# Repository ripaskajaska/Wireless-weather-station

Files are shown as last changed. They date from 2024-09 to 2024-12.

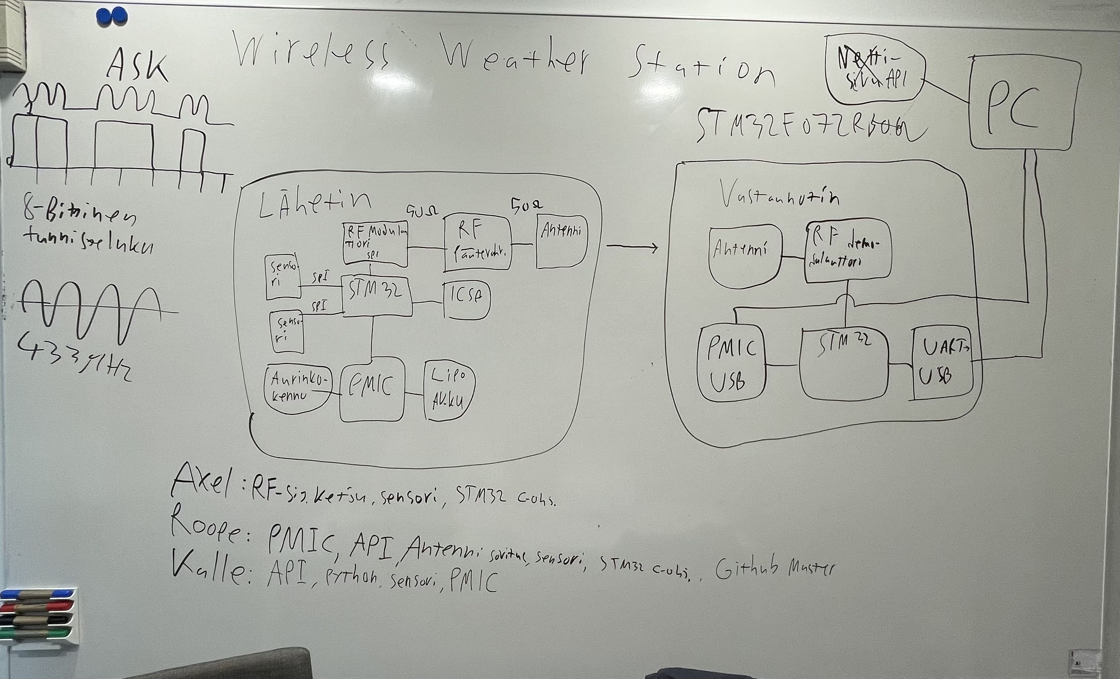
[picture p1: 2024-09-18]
plan_120924.jpeg

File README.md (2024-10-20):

# Wireless-weather-station
Aalto University’s ELEC-8701 Elektronics workshop courses repository for Axel Soderberg, Roope Jaskari and Kalle Aro

# Basic git usage for this project:

Sections 1 to 2 are done on the command line
# 1. Initialization 

If you don't have an ssh key yet follow the instruction in [this link](https://www.howtogeek.com/762863/how-to-generate-ssh-keys-in-windows-10-and-windows-11/)
Add this ssh key to your GitHub SSH keys and proceed.

## clone project
```
git clone git@github.com:<yourusername>/Wireless-weather-station.git
```

Go to the cloned repository > "Wireless-weather-station" (default name)

## Make your own branch
```
git branch <your own branch name here>
```
```
git checkout <your own branch name here>
```
# 2. Working with git

When you want to commit something, first check out the changes you have made.
```
git status
```
After this add the files you'd like to commit

```
git add <your file/folder in the git initialized folder>
```
Commit
```
git commit -m "<your required message here>"
```
And if this is your first push to the git repository use this to also set your upstream:

```
git push --set-upstream origin
```
Otherwise:
```
git push
```

# 3. Merging with main
After a successful commit and push, if you'd like to begin a merge request with your branch and the main branch, navigate to your branch in GitHub from this dropdown:



And then make a pull request here: 



After this, notify the other contributors about the pull request in order to get their approval on the matter. Success!

# In addition one can delete their own branch from the GitHub to start a new addition to the project from a clean table. 
# DO NOT TRY TO DELETE THE MAIN BRANCH!

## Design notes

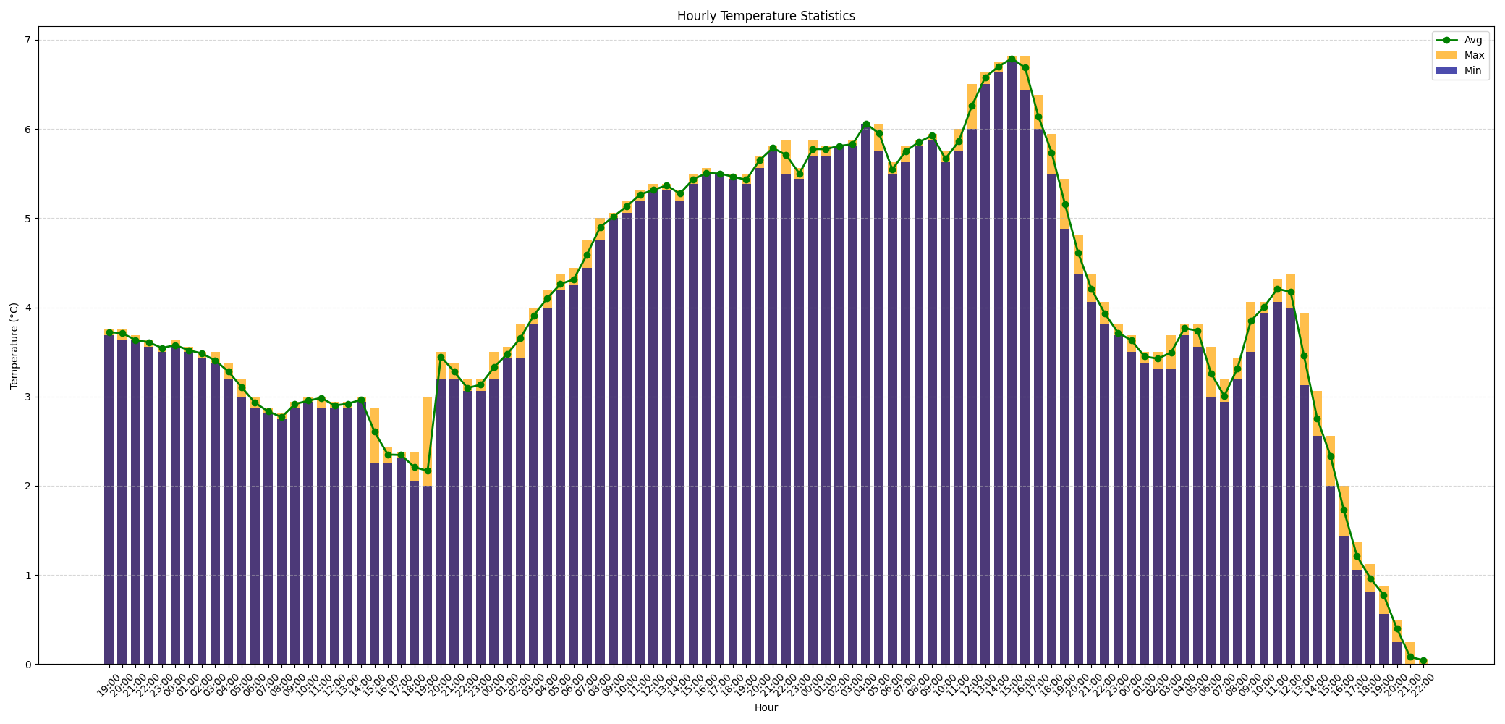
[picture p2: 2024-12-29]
Hrly_temp.png

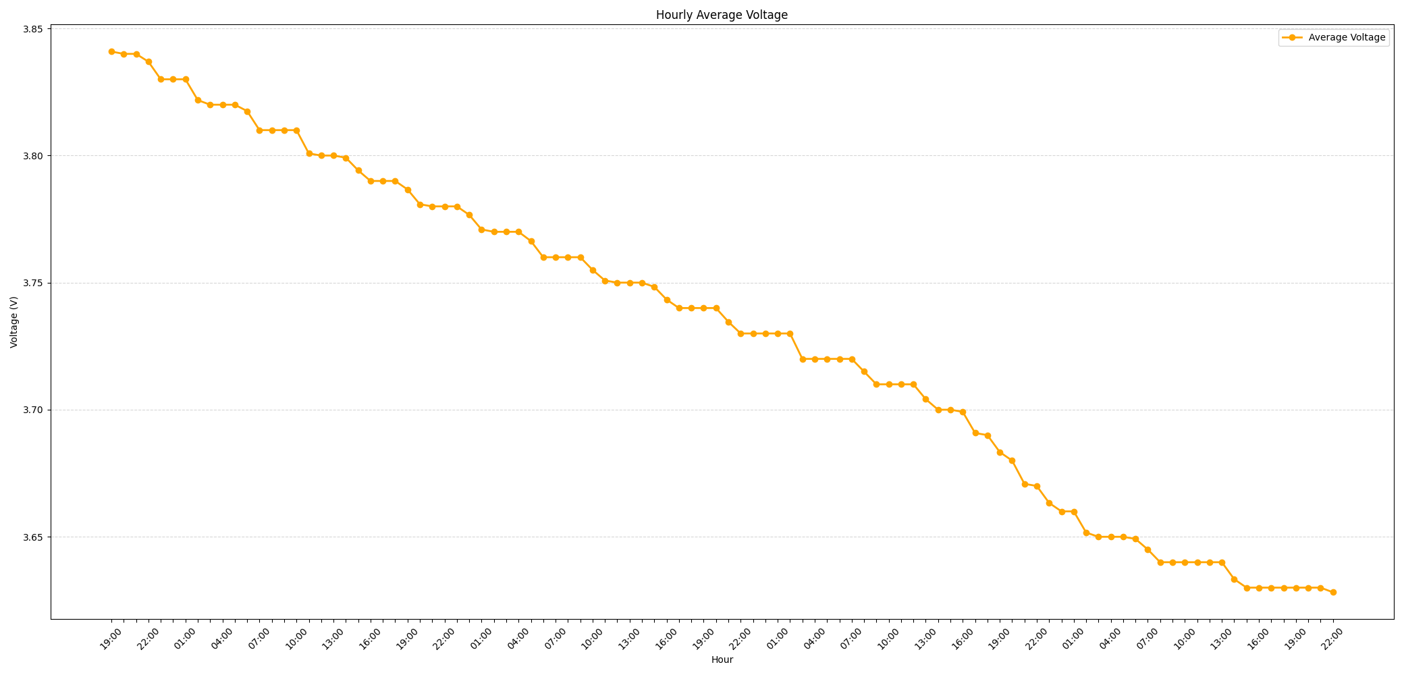
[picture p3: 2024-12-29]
Hrly_avg_vol.png

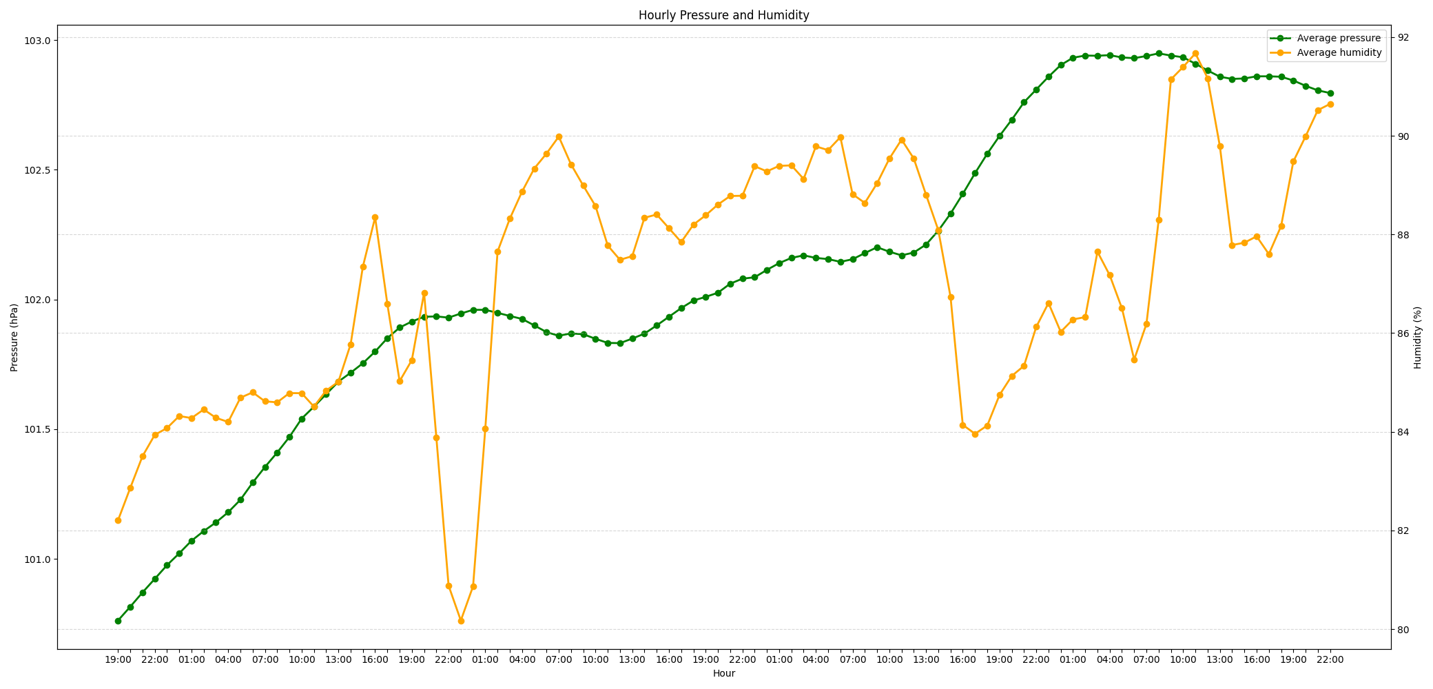
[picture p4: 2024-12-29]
Hrly_avg_pres_and_hum.png

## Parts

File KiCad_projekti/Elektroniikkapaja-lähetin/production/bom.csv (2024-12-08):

Designator | Footprint | Quantity | Value | LCSC Part #
BT1 | BatteryHolder_MPD_BH-18650-PC2 | 1 | Battery_Cell
C1, C2 | 0805 | 2 | 22pF
C10, C17, C21, C22, C4 | 0805 | 5 | 100nF
C11, C12, C15 | 0805 | 3 | 1uF
C13, C20, C6, C7 | 0805 | 4 | 10uF
C14, C16 | 0805 | 2 | 1nF
C18, C19 | 1206 | 2 | 4.7uF
C3 | 0805 | 1 | 4.7pF
C5 | 0805 | 1 | 10pF
C8, C9 | 0805 | 2 | 18pF
D1, D3 | 0805 | 2 | LED
D2 | D_DO-35_SOD27_P7.62mm_Horizontal | 1 | 5.1V Zener
D4 | D_DO-35_SOD27_P7.62mm_Horizontal | 1 | 1N4148
H1, H2, H3, H4 | MountingHole_2.2mm_M2 | 4 | MountingHole
J1 | SMA_Amphenol_901-143_Horizontal | 1 | Conn_Coaxial
J3 | PinHeader_1x06_P2.54mm_Vertical | 1 | Conn_01x06_Pin
J4 | PinHeader_1x04_P2.54mm_Vertical | 1 | Conn_01x04_Pin
J5 | PinSocket_1x07_P2.54mm_Vertical | 1 | Conn_01x07_Socket
J6 | PinHeader_1x02_P2.54mm_Vertical | 1 | Conn_01x02_Pin
J7 | PinHeader_1x08_P2.54mm_Vertical | 1 | Conn_01x08_Pin
J8 | PinHeader_1x02_P2.54mm_Vertical | 1 | Solar_panel_connector
J9 | PinHeader_2x03_P2.54mm_Vertical | 1 | AVR-ISP-6
L1 | 0805 | 1 | 82nH
L2 | 0805 | 1 | 470nF
L3 | WE-PD2_1054 | 1 | 10uH
Q1, Q2 | SOT-23-3 | 2 | SSM3J371R
R1 | 0805 | 1 | 10k
R10, R17 | 0805 | 2 | 2k2
R11 | 0805 | 1 | R
R12 | R_Axial_DIN0204_L3.6mm_D1.6mm_P2.54mm_Vertical | 1 | R_Photo
R13 | 0805 | 1 | 150k
R14 | 0805 | 1 | 300k
R15 | 0805 | 1 | 330r
R16, R18, R19, R20, R21, R4 | 0805 | 6 | 4k7
R2 | 0805 | 1 | 150r
R3, R5, R6 | 0805 | 3 | 1k
R7 | 0805 | 1 | 680mohm
R8 | 0805 | 1 | 160k
R9 | 0805 | 1 | 68k
SW1 | SW_CuK_JS202011CQN_DPDT_Straight | 1 | SW_SPDT
SW_RESET1 | SW_SPST_TL3305A | 1 | SW_Push
U1 | TQFP-44_10x10mm_P0.8mm | 1 | ATmega644-20A
U2 | TSSOP-8_4.4x3mm_P0.65mm | 1 | ~
U3 | SOT-23-6_Handsoldering | 1 | Micrf113
U4 | TO-92_Inline | 1 | MCP1700x-330xxTO
U5 | TO-92_Inline | 1 | DS18S20
U6 | SOT-23-5 | 1 | MCP73831-2-OT
U7 | DIP-14_W7.62mm | 1 | SN74LS07N
Y1 | Crystal_HC49-U_Vertical | 1 | Crystal 16MHz
Y2 | Crystal_HC49-U_Vertical | 1 | Crystal 13.56MHz

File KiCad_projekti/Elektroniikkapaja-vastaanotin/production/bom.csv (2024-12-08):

Designator | Footprint | Quantity | Value | LCSC Part #
C1, C2 | 0805 | 2 | 47pF
C10, C11, C12, C14, C18, C20, C21, C4, C5 | 0805 | 9 | 100nF
C13 | 0805 | 1 | 10uF
C15, C16 | 0805 | 2 | 22pF
C17, C3 | 1206 | 2 | 4.7uF
C19 | 0805 | 1 | 1.2pF
C6, C7 | 0805 | 2 | 1uF
C8, C9 | 0805 | 2 | 10pF
D1, D2, D3, D4, D5 | 0805 | 5 | LED
H1, H2, H3, H4 | MountingHole_2.2mm_M2 | 4 | MountingHole
J1 | USB_B_Lumberg_2411_02_Horizontal | 1 | USB_B
J2 | SMA_Amphenol_901-143_Horizontal | 1 | Conn_Coaxial
J3 | JST_SH_SM04B-SRSS-TB_1x04-1MP_P1.00mm_Horizontal | 1 | Conn_01x04_Pin
J4 | PinHeader_2x03_P2.54mm_Vertical | 1 | AVR-ISP-6
J5 | PinHeader_1x04_P2.54mm_Vertical | 1 | Conn_01x04_Pin
J6 | PinHeader_1x06_P2.54mm_Vertical | 1 | Conn_01x06_Pin
J7 | PinHeader_1x08_P2.54mm_Vertical | 1 | Conn_01x08_Pin
JP1, JP2 | SolderJumper-3_P1.3mm_Open_RoundedPad1.0x1.5mm_NumberLabels | 2 | SolderJumper_3_Open
L2 | 0805 | 1 | 39nH
R1, R2 | 0805 | 2 | 560R
R10, R11, R8, R9 | 0805 | 4 | 4k7
R12 | 0805 | 1 | 10k
R13, R5 | 0805 | 2 | 150r
R3, R4 | 0805 | 2 | 27R
R6 | 0805 | 1 | 100r
R7 | 0805 | 1 | 330r
SW_RESET1 | SW_SPST_TL3305A | 1 | SW_Push
U1 | TQFP-32_7x7mm_P0.8mm | 1 | ATmega328PB-A
U2 | QSOP-16_3.9x4.9mm_P0.635mm | 1 | MICRF220AYQS
U3 | SSOP-16_3.9x4.9mm_P0.635mm | 1 | FT230XS
U4 | TO-92_Inline | 1 | MCP1700x-330xxTO
U5 | SOIC-8_3.9x4.9mm_P1.27mm | 1 | TL072
U6 | DIP-14_W7.62mm | 1 | SN74LS07N
Y1 | Crystal_SMD_HC49-SD_HandSoldering | 1 | 13.52313MHz
Y2 | Crystal_HC49-U_Vertical | 1 | Crystal 16MHz

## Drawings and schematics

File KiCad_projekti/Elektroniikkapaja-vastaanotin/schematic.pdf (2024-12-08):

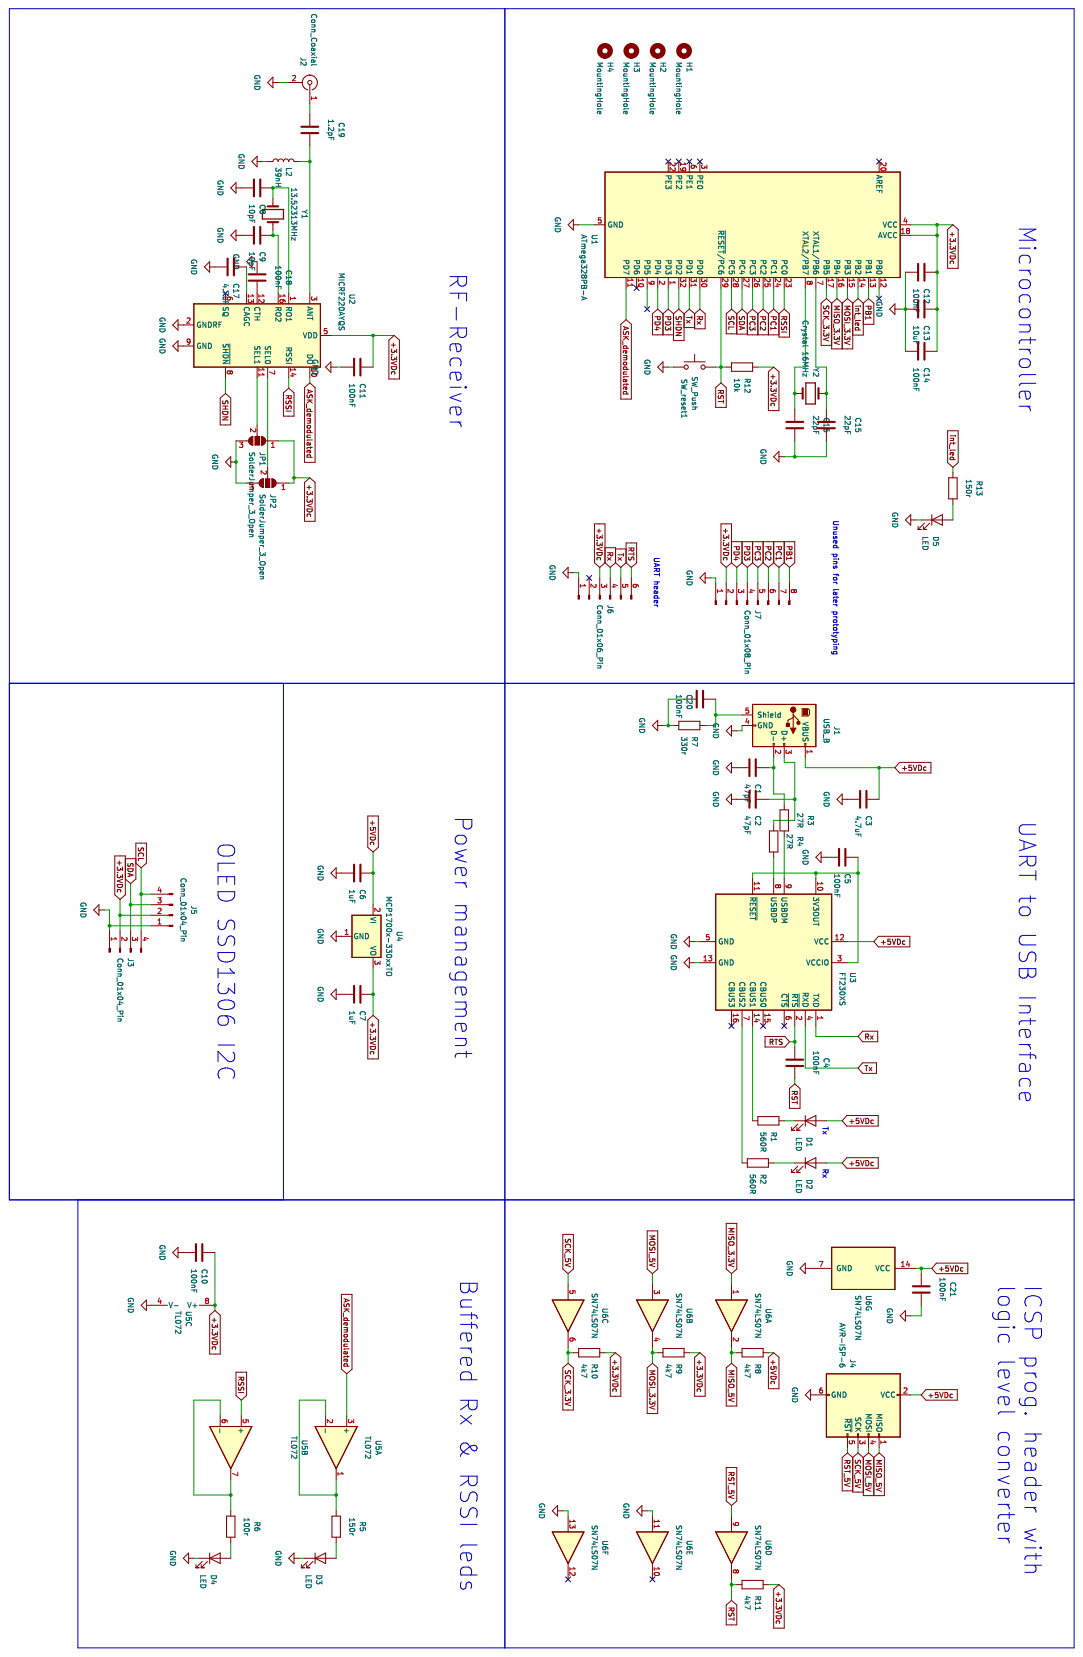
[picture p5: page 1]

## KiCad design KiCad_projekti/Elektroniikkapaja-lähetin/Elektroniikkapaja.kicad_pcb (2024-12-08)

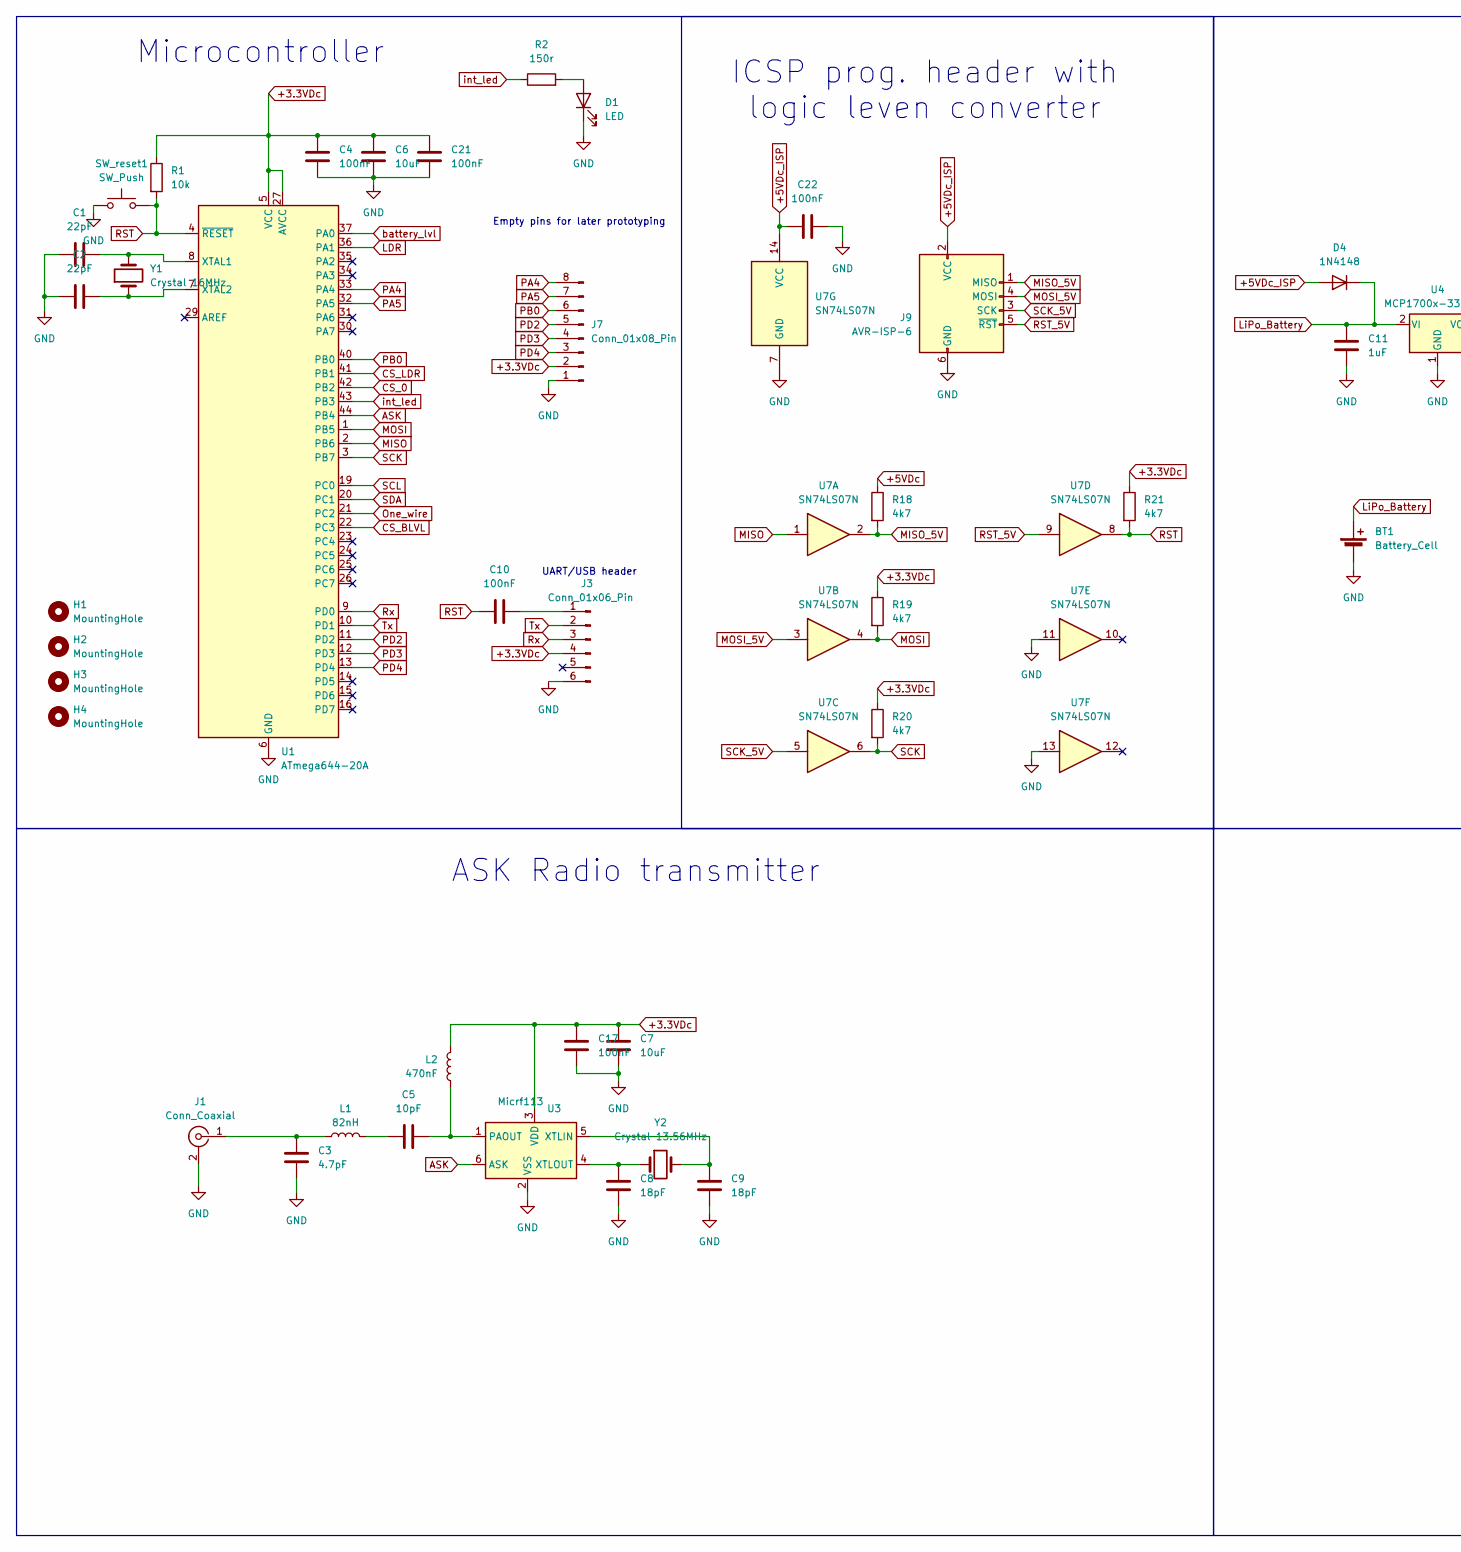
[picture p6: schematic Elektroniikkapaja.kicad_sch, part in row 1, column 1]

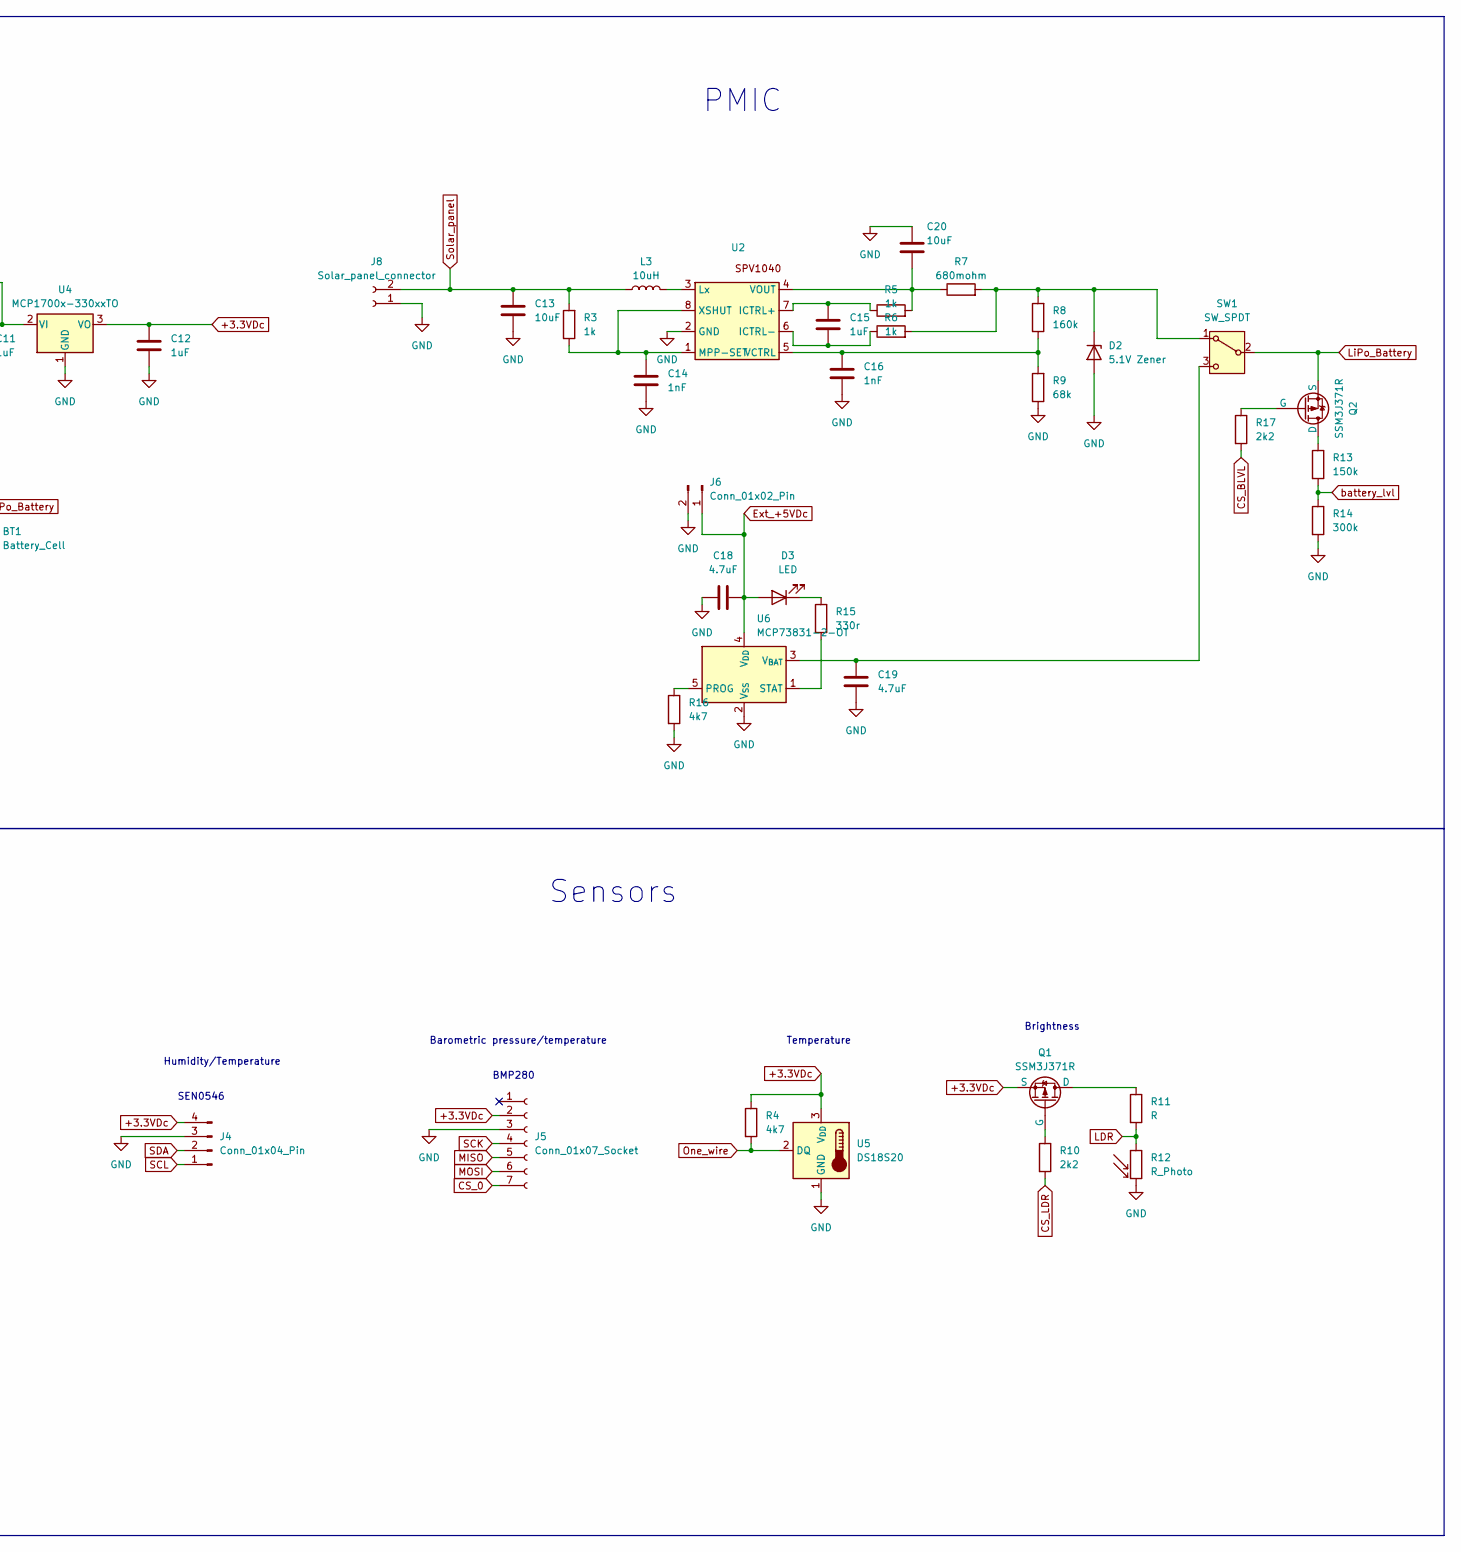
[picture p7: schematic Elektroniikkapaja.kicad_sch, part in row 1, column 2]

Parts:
BT1: Battery_Cell; BatteryHolder_MPD_BH-18650-PC2
C1, C2: 22pF; C_0805_2012Metric_Pad1.18x1.45mm_HandSolder
C3: 4.7pF; C_0805_2012Metric_Pad1.18x1.45mm_HandSolder
C4, C10, C17, C21, C22: 100nF; C_0805_2012Metric_Pad1.18x1.45mm_HandSolder
C5: 10pF; C_0805_2012Metric_Pad1.18x1.45mm_HandSolder
C6, C7, C13, C20: 10uF; C_0805_2012Metric_Pad1.18x1.45mm_HandSolder
C8, C9: 18pF; C_0805_2012Metric_Pad1.18x1.45mm_HandSolder
C11, C12, C15: 1uF; C_0805_2012Metric_Pad1.18x1.45mm_HandSolder
C14, C16: 1nF; C_0805_2012Metric_Pad1.18x1.45mm_HandSolder
C18, C19: 4.7uF; C_1206_3216Metric_Pad1.33x1.80mm_HandSolder
D1, D3: LED; LED_0805_2012Metric_Pad1.15x1.40mm_HandSolder
D2: 5.1V Zener; D_DO-35_SOD27_P7.62mm_Horizontal
D4: 1N4148; D_DO-35_SOD27_P7.62mm_Horizontal
H1, H2, H3, H4: MountingHole; MountingHole_2.2mm_M2
J1: Conn_Coaxial; SMA_Amphenol_901-143_Horizontal
J3: Conn_01x06_Pin; PinHeader_1x06_P2.54mm_Vertical
J4: Conn_01x04_Pin; PinHeader_1x04_P2.54mm_Vertical
J5: Conn_01x07_Socket; PinSocket_1x07_P2.54mm_Vertical
J6: Conn_01x02_Pin; PinHeader_1x02_P2.54mm_Vertical
J7: Conn_01x08_Pin; PinHeader_1x08_P2.54mm_Vertical
J8: Solar_panel_connector; PinHeader_1x02_P2.54mm_Vertical
J9: AVR-ISP-6; PinHeader_2x03_P2.54mm_Vertical
L1: 82nH; L_0805_2012Metric_Pad1.15x1.40mm_HandSolder
L2: 470nF; L_0805_2012Metric_Pad1.15x1.40mm_HandSolder
L3: 10uH; WE-PD2_1054
Q1, Q2: SSM3J371R; SOT-23-3
R1: 10k; R_0805_2012Metric_Pad1.20x1.40mm_HandSolder
R2: 150r; R_0805_2012Metric_Pad1.20x1.40mm_HandSolder
R3, R5, R6: 1k; R_0805_2012Metric_Pad1.20x1.40mm_HandSolder
R4, R16, R18, R19, R20, R21: 4k7; R_0805_2012Metric_Pad1.20x1.40mm_HandSolder
R7: 680mohm; R_0805_2012Metric_Pad1.20x1.40mm_HandSolder
R8: 160k; R_0805_2012Metric_Pad1.20x1.40mm_HandSolder
R9: 68k; R_0805_2012Metric_Pad1.20x1.40mm_HandSolder
R10, R17: 2k2; R_0805_2012Metric_Pad1.20x1.40mm_HandSolder
R11: R; R_0805_2012Metric_Pad1.20x1.40mm_HandSolder
R12: R_Photo; R_Axial_DIN0204_L3.6mm_D1.6mm_P2.54mm_Vertical
R13: 150k; R_0805_2012Metric_Pad1.20x1.40mm_HandSolder
R14: 300k; R_0805_2012Metric_Pad1.20x1.40mm_HandSolder
R15: 330r; R_0805_2012Metric_Pad1.20x1.40mm_HandSolder
SW1: SW_SPDT; SW_CuK_JS202011CQN_DPDT_Straight
SW_reset1: SW_Push; SW_SPST_TL3305A
U1: ATmega644-20A; TQFP-44_10x10mm_P0.8mm
U2: TSSOP-8_4.4x3mm_P0.65mm
U3: Micrf113; SOT-23-6_Handsoldering
U4: MCP1700x-330xxTO; TO-92_Inline
U5: DS18S20; TO-92_Inline
U6: MCP73831-2-OT; SOT-23-5
U7: SN74LS07N; DIP-14_W7.62mm
Y1: Crystal 16MHz; Crystal_HC49-U_Vertical
Y2: Crystal 13.56MHz; Crystal_HC49-U_Vertical

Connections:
+3.3VDc: C4.1, C6.1, C7.1, C12.1, C17.2, C21.1, J3.4, J4.4, J5.2, J7.2, L2.1, Q1.2 (S), R1.1, R4.1, R19.1, R20.1, R21.1, U1.5 (VCC), U1.17 (VCC), U1.27 (AVCC), U1.38 (VCC), U3.3 (VDD), U4.3 (VO), U5.3 (V_{DD})
+5VDc: R18.1
+5VDc_ISP: C22.1, D4.2 (A), J9.2 (VCC), U7.14 (VCC)
ASK: U1.44 (PB4), U3.6 (ASK)
CS_0: J5.7, U1.42 (PB2)
CS_BLVL: R17.2, U1.22 (PC3)
CS_LDR: R10.2, U1.41 (PB1)
Ext_+5VDc: C18.1, D3.2 (A), J6.1, U6.4 (V_{DD})
GND: BT1.2 (-), C1.1, C2.1, C3.2, C4.2, C6.2, C7.2, C8.2, C9.2, C11.2, C12.2, C13.2, C14.2, C16.2, C17.1, C18.2, C19.2, C20.1, C21.2, C22.2, D1.1 (K), D2.2 (A), J1.2 (Ext), J3.6, J4.3, J5.3, J6.2, J7.1, J8.1, J9.6 (GND), R9.1, R12.2, R14.2, R16.2, SW_reset1.1, U1.6 (GND), U1.18 (GND), U1.28 (GND), U1.39 (GND), U2.2 (GND), U3.2 (VSS), U4.1 (GND), U5.1 (GND), U6.2 (V_{SS}), U7.7 (GND), U7.11, U7.13
LDR: R11.2, R12.1, U1.36 (PA1)
LiPo_Battery: BT1.1 (+), C11.1, D4.1 (K), Q2.2 (S), SW1.2 (B), U4.2 (VI)
MISO: J5.5, U1.2 (PB6), U7.1
MISO_5V: J9.1 (MISO), R18.2, U7.2
MOSI: J5.6, R19.2, U1.1 (PB5), U7.4
MOSI_5V: J9.4 (MOSI), U7.3
unnamed: C5.1, L1.2
unnamed: D1.2 (A), R2.2
unnamed: D2.1 (K), R6.2, R7.2, R8.2, SW1.1 (A)
unnamed: D3.1 (K), R15.1
unnamed: C3.1, J1.1 (In), L1.1
unnamed: C10.2, J3.1
unnamed: Q1.3 (D), R11.1
unnamed: Q1.1 (G), R10.1
unnamed: Q2.3 (D), R13.1
unnamed: Q2.1 (G), R17.1
unnamed: C19.1, SW1.3 (C), U6.3 (V_{BAT})
unnamed: C1.2, U1.8 (XTAL1), Y1.2
unnamed: C2.2, U1.7 (XTAL2), Y1.1
unnamed: C15.1, R5.1, U2.7 (ICTRL+)
unnamed: C15.2, R6.1, U2.6 (ICTRL-)
unnamed: L3.2, U2.3 (Lx)
unnamed: C14.1, R3.1, U2.1 (MPP-SET), U2.8 (XSHUT)
unnamed: C16.1, R8.1, R9.2, U2.5 (VCTRL)
unnamed: C20.2, R5.2, R7.1, U2.4 (VOUT)
unnamed: C5.2, L2.2, U3.1 (PAOUT)
unnamed: C9.1, U3.5 (XTLIN), Y2.2
unnamed: C8.1, U3.4 (XTLOUT), Y2.1
unnamed: R16.1, U6.5 (PROG)
unnamed: R15.2, U6.1 (STAT)
One_wire: R4.2, U1.21 (PC2), U5.2 (DQ)
PA4: J7.8, U1.33 (PA4)
PA5: J7.7, U1.32 (PA5)
PB0: J7.6, U1.40 (PB0)
PD2: J7.5, U1.11 (PD2)
PD3: J7.4, U1.12 (PD3)
PD4: J7.3, U1.13 (PD4)
RST: C10.1, R1.2, R21.2, SW_reset1.2, U1.4 (~RESET), U7.8
RST_5V: J9.5 (~RST), U7.9
Rx: J3.3, U1.9 (PD0)
SCK: J5.4, R20.2, U1.3 (PB7), U7.6
SCK_5V: J9.3 (SCK), U7.5
SCL: J4.1, U1.19 (PC0)
SDA: J4.2, U1.20 (PC1)
Solar_panel: C13.1, J8.2, L3.1, R3.2
Tx: J3.2, U1.10 (PD1)
battery_lvl: R13.2, R14.1, U1.37 (PA0)
int_led: R2.1, U1.43 (PB3)

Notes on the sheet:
Temperature
Empty pins for later prototyping
UART/USB header
Microcontroller
Humidity/Temperature
PMIC
Barometric pressure/temperature
BMP280
ICSP prog. header with logic leven converter
ASK Radio transmitter
SEN0546
Brightness
Sensors

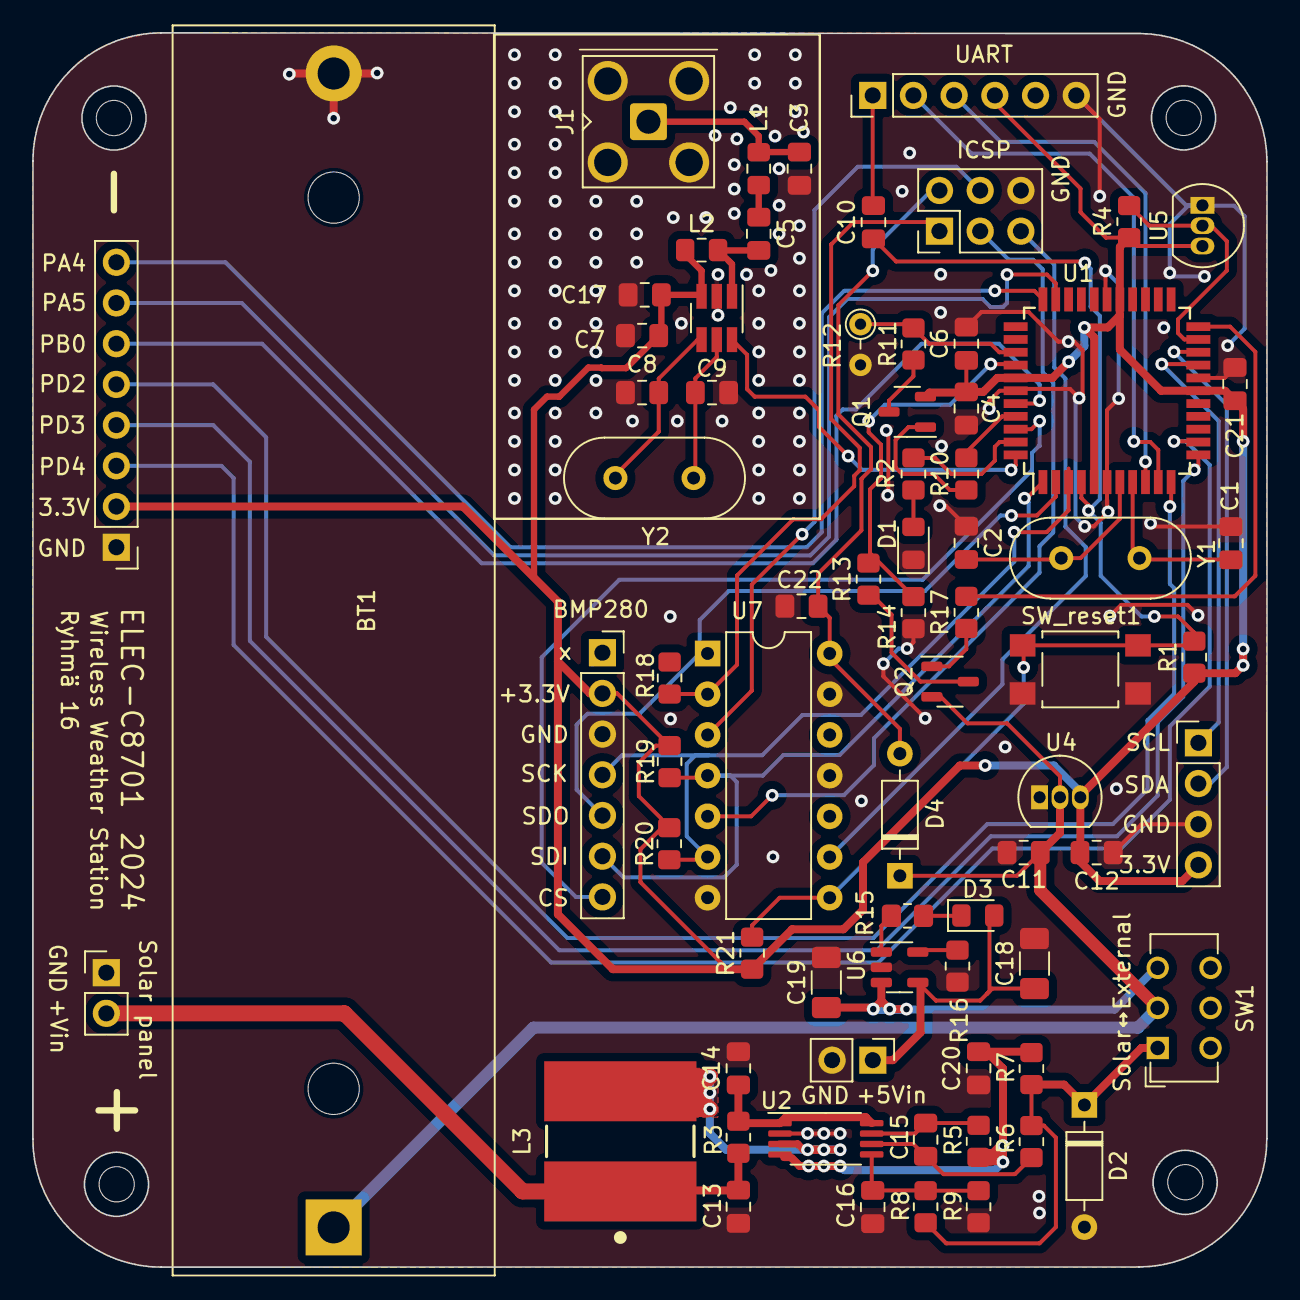
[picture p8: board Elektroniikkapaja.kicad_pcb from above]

Board: 2 copper layers, 77.0 x 77.0 mm, 76 parts (0 on the bottom side), 56 nets.

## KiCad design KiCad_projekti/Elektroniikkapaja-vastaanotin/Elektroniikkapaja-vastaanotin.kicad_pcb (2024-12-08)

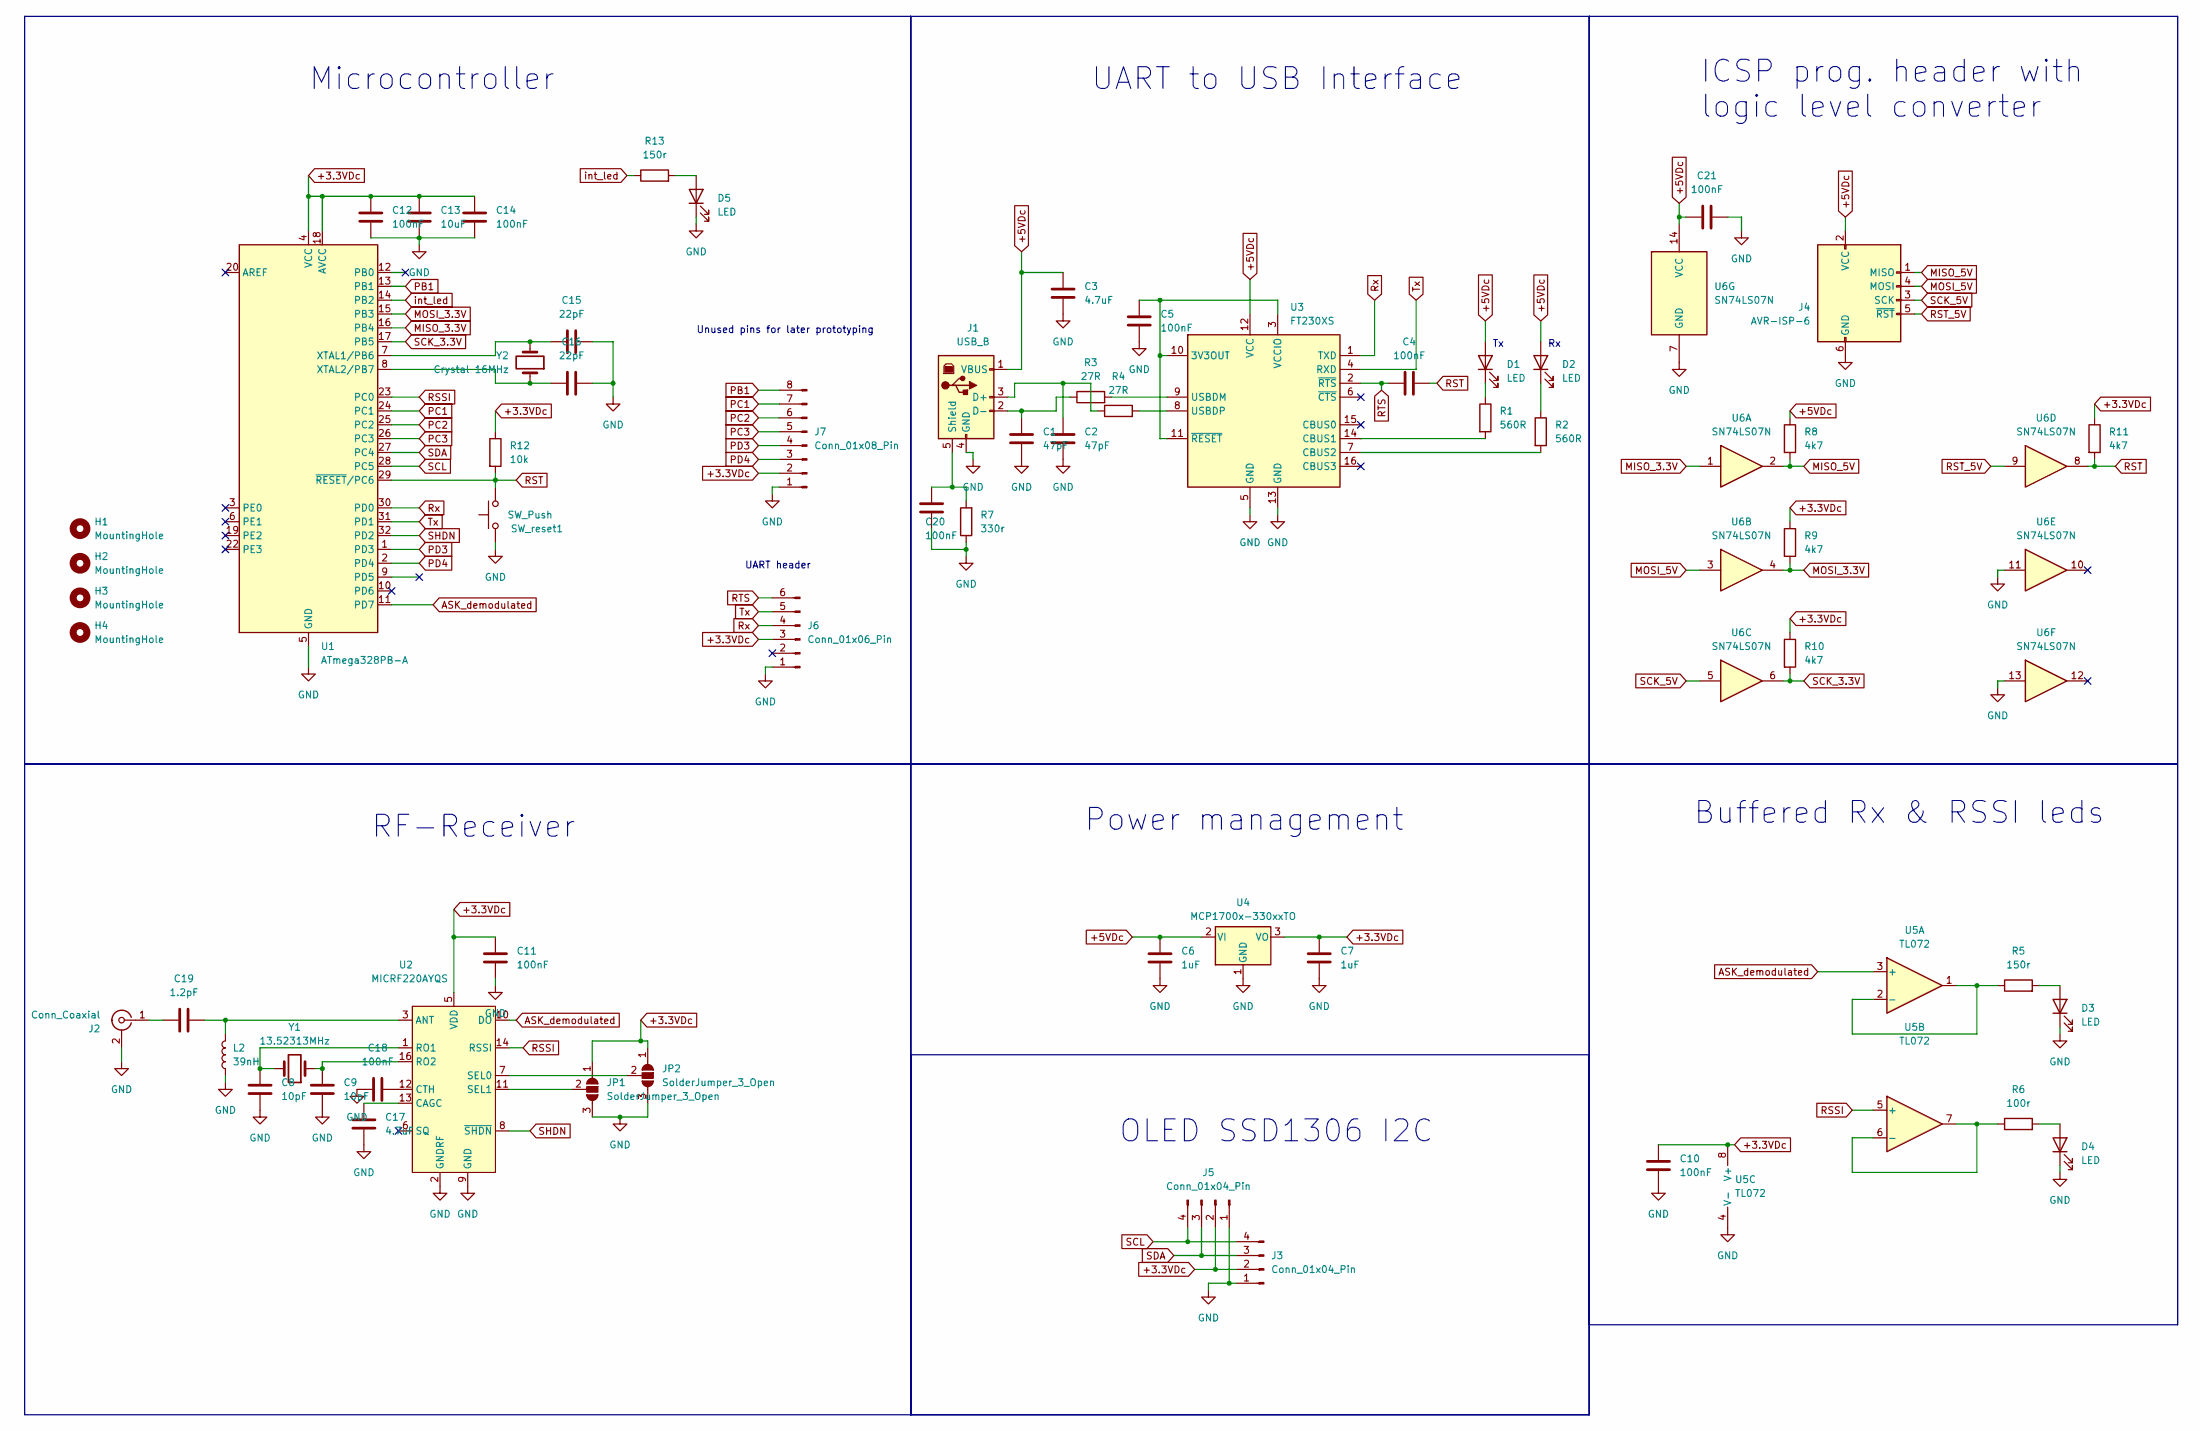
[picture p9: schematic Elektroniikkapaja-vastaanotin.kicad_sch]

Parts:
C1, C2: 47pF; C_0805_2012Metric_Pad1.18x1.45mm_HandSolder
C3, C17: 4.7uF; C_1206_3216Metric_Pad1.33x1.80mm_HandSolder
C4, C5, C10, C11, C12, C14, C18, C20, C21: 100nF; C_0805_2012Metric_Pad1.18x1.45mm_HandSolder
C6, C7: 1uF; C_0805_2012Metric_Pad1.18x1.45mm_HandSolder
C8, C9: 10pF; C_0805_2012Metric_Pad1.18x1.45mm_HandSolder
C13: 10uF; C_0805_2012Metric_Pad1.18x1.45mm_HandSolder
C15, C16: 22pF; C_0805_2012Metric_Pad1.18x1.45mm_HandSolder
C19: 1.2pF; C_0805_2012Metric_Pad1.18x1.45mm_HandSolder
D1, D2, D3, D4, D5: LED; LED_0805_2012Metric_Pad1.15x1.40mm_HandSolder
H1, H2, H3, H4: MountingHole; MountingHole_2.2mm_M2
J1: USB_B; USB_B_Lumberg_2411_02_Horizontal
J2: Conn_Coaxial; SMA_Amphenol_901-143_Horizontal
J3: Conn_01x04_Pin; JST_SH_SM04B-SRSS-TB_1x04-1MP_P1.00mm_Horizontal
J4: AVR-ISP-6; PinHeader_2x03_P2.54mm_Vertical
J5: Conn_01x04_Pin; PinHeader_1x04_P2.54mm_Vertical
J6: Conn_01x06_Pin; PinHeader_1x06_P2.54mm_Vertical
J7: Conn_01x08_Pin; PinHeader_1x08_P2.54mm_Vertical
JP1, JP2: SolderJumper_3_Open; SolderJumper-3_P1.3mm_Open_RoundedPad1.0x1.5mm_NumberLabels
L2: 39nH; C_0805_2012Metric_Pad1.18x1.45mm_HandSolder
R1, R2: 560R; R_0805_2012Metric_Pad1.20x1.40mm_HandSolder
R3, R4: 27R; R_0805_2012Metric_Pad1.20x1.40mm_HandSolder
R5: 150r; R_0805_2012Metric_Pad1.20x1.40mm_HandSolder
R6: 100r; R_0805_2012Metric_Pad1.20x1.40mm_HandSolder
R7: 330r; R_0805_2012Metric_Pad1.20x1.40mm_HandSolder
R8, R9, R10, R11: 4k7; R_0805_2012Metric_Pad1.20x1.40mm_HandSolder
R12: 10k; R_0805_2012Metric_Pad1.20x1.40mm_HandSolder
R13: 150r; R_0805_2012Metric
SW_reset1: SW_Push; SW_SPST_TL3305A
U1: ATmega328PB-A; TQFP-32_7x7mm_P0.8mm
U2: MICRF220AYQS; QSOP-16_3.9x4.9mm_P0.635mm
U3: FT230XS; SSOP-16_3.9x4.9mm_P0.635mm
U4: MCP1700x-330xxTO; TO-92_Inline
U5: TL072; SOIC-8_3.9x4.9mm_P1.27mm
U6: SN74LS07N; DIP-14_W7.62mm
Y1: 13.52313MHz; Crystal_SMD_HC49-SD_HandSoldering
Y2: Crystal 16MHz; Crystal_HC49-U_Vertical

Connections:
+3.3VDc: C7.1, C10.1, C11.1, C12.1, C13.1, C14.1, J3.2, J5.2, J6.3, J7.2, JP1.1 (A), JP2.1 (A), R9.1, R10.1, R11.1, R12.1, U1.4 (VCC), U1.18 (AVCC), U2.5 (VDD), U4.3 (VO), U5.8 (V+)
+5VDc: C3.1, C6.1, C21.1, D1.2 (A), D2.2 (A), J1.1 (VBUS), J4.2 (VCC), R8.1, U3.12 (VCC), U4.2 (VI), U6.14 (VCC)
ASK_demodulated: U1.11 (PD7), U2.10 (DO), U5.3 (+)
GND: C1.2, C2.2, C3.2, C5.2, C6.2, C7.2, C8.2, C9.2, C10.2, C11.2, C12.2, C13.2, C14.2, C15.1, C16.1, C17.2, C18.1, C20.2, C21.2, D3.1 (K), D4.1 (K), D5.1 (K), J1.4 (GND), J2.2 (Ext), J3.1, J4.6 (GND), J5.1, J6.1, J7.1, JP1.3 (B), JP2.3 (B), L2.1, R7.1, SW_reset1.1, U1.5 (GND), U1.21 (GND), U2.2 (GNDRF), U2.4 (GNDRF), U2.9 (GND), U3.5 (GND), U3.13 (GND), U4.1 (GND), U5.4 (V-), U6.7 (GND), U6.11, U6.13
MISO_3.3V: U1.16 (PB4), U6.1
MISO_5V: J4.1 (MISO), R8.2, U6.2
MOSI_3.3V: R9.2, U1.15 (PB3), U6.4
MOSI_5V: J4.4 (MOSI), U6.3
unnamed: D1.1 (K), R1.1
unnamed: D2.1 (K), R2.1
unnamed: D3.2 (A), R5.2
unnamed: D4.2 (A), R6.2
unnamed: D5.2 (A), R13.2
unnamed: C2.1, J1.3 (D+), R4.1
unnamed: C1.1, J1.2 (D-), R3.1
unnamed: C20.1, J1.5 (Shield), R7.2
unnamed: C19.2, J2.1 (In)
unnamed: JP1.2 (C), U2.11 (SEL1)
unnamed: JP2.2 (C), U2.7 (SEL0)
unnamed: C15.2, U1.7 (XTAL1/PB6), Y2.2
unnamed: C16.2, U1.8 (XTAL2/PB7), Y2.1
unnamed: C19.1, L2.2, U2.3 (ANT)
unnamed: C17.1, U2.13 (CAGC)
unnamed: C18.2, U2.12 (CTH)
unnamed: C8.1, U2.1 (RO1), Y1.2
unnamed: C9.1, U2.16 (RO2), Y1.1
unnamed: C5.1, U3.3 (VCCIO), U3.10 (3V3OUT), U3.11 (~RESET)
unnamed: R1.2, U3.14 (CBUS1)
unnamed: R2.2, U3.7 (CBUS2)
unnamed: R3.2, U3.9 (USBDM)
unnamed: R4.2, U3.8 (USBDP)
unnamed: R5.1, U5.1, U5.2 (-)
unnamed: R6.1, U5.6 (-), U5.7
PB1: J7.8, U1.13 (PB1)
PC1: J7.7, U1.24 (PC1)
PC2: J7.6, U1.25 (PC2)
PC3: J7.5, U1.26 (PC3)
PD3: J7.4, U1.1 (PD3)
PD4: J7.3, U1.2 (PD4)
RSSI: U1.23 (PC0), U2.14 (RSSI), U5.5 (+)
RST: C4.2, R11.2, R12.2, SW_reset1.2, U1.29 (~RESET/PC6), U6.8
RST_5V: J4.5 (~RST), U6.9
RTS: C4.1, J6.6, U3.2 (~RTS)
Rx: J6.4, U1.30 (PD0), U3.1 (TXD)
SCK_3.3V: R10.2, U1.17 (PB5), U6.6
SCK_5V: J4.3 (SCK), U6.5
SCL: J3.4, J5.4, U1.28 (PC5)
SDA: J3.3, J5.3, U1.27 (PC4)
SHDN: U1.32 (PD2), U2.8 (~SHDN)
Tx: J6.5, U1.31 (PD1), U3.4 (RXD)
int_led: R13.1, U1.14 (PB2)

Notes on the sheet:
OLED SSD1306 I2C
Unused pins for later prototyping
UART header
Buffered Rx & RSSI leds
ICSP prog. header with logic level converter
UART to USB Interface
RF-Receiver
Power management
Microcontroller

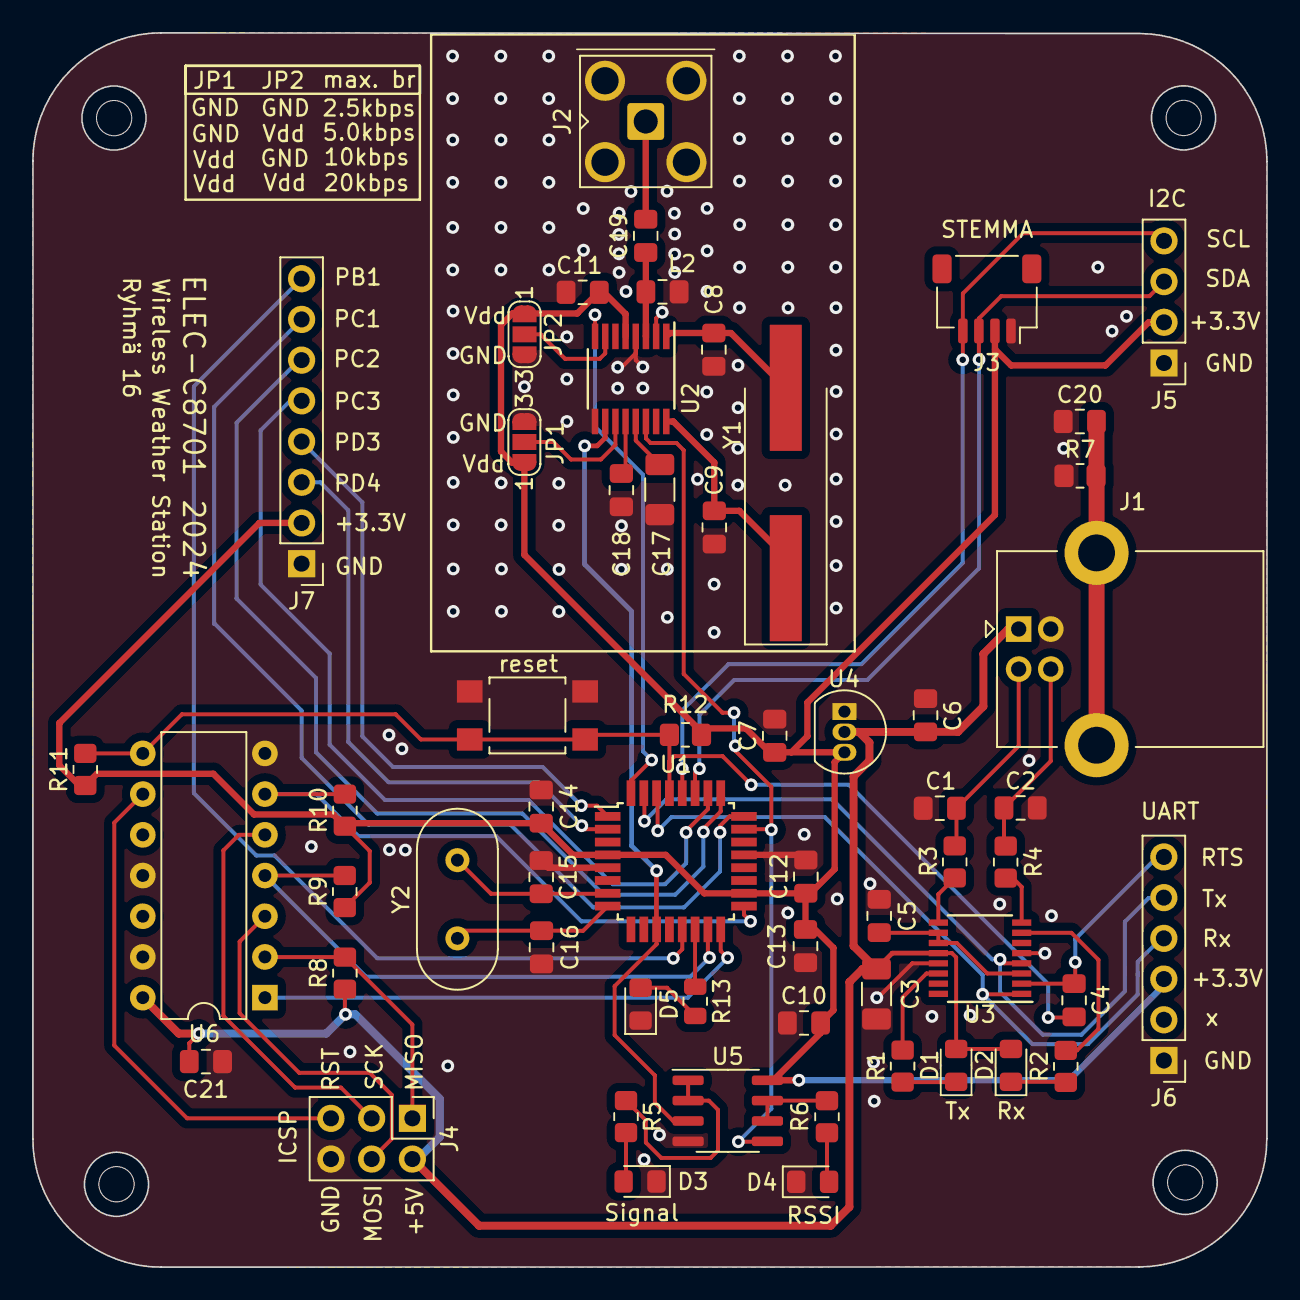
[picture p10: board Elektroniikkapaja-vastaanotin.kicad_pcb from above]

Board: 2 copper layers, 77.0 x 77.0 mm, 62 parts (0 on the bottom side), 51 nets.

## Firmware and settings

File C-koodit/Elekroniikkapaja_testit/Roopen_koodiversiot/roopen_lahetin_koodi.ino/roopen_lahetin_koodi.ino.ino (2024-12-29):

#include <OneWire.h>
#include <RH_ASK.h>
#include <DallasTemperature.h>
#include <Adafruit_BMP280.h>
#include <Wire.h>
#include <SPI.h>
#include <avr/io.h>
#include <avr/interrupt.h>
#include <avr/sleep.h>


// Pin definitions for ATmega644A
#define ONE_WIRE_BUS 18         // For Dallas DS1820
#define BMP_CS PB2               // Use PB4 as Chip Select for BMP280
#define ADDRESS 0x40             // SEN0546 I2C address

// Global variables
float temp = 0.0;
float pressure = 0.0;
float humidity = 0.0;
float battery_voltage = 0.0;
uint8_t buf[4] = {0};
float floatValueArray[4] = {0.0};
uint16_t rawHumidity;
volatile uint16_t timerOverflowCount = 0;  // Overflow counter


// Initialize Dallas Temp DS1820
OneWire oneWire(ONE_WIRE_BUS);        // OneWire instance
DallasTemperature sensors(&oneWire); // Dallas Temperature instance

// Initialize BMP280
Adafruit_BMP280 bmp(BMP_CS); // Hardware SPI

// Create an instance of the RadioHead driver
RH_ASK driver(2000, PA2, 4, PA3);  // (bitrate, RX pin, TX pin, PTT pin)

// Function to send a float array

// Function prototypes
void measure_temperature(float* temp_ptr);
void measure_barometric_pressure(float* pressure_ptr);
void measure_relative_humidity(float* humidity_ptr);
void measure_battery_voltage(float* battery_voltage_ptr);
uint8_t readReg(uint8_t reg, void* pBuf, size_t size);

void sendFloatArray() {
  driver.send((uint8_t*)floatValueArray, 4 * sizeof(float));
  driver.waitPacketSent();
}

void setupTimer1() {
    cli(); // Disable interrupts
    // Configure Timer1
    TCCR1B |= (1 << CS12) | (1 << CS10); // Prescaler = 1024
    TIMSK1 |= (1 << TOIE1);              // Enable Timer1 Overflow Interrupt
    TCNT1 = 0;                           // Reset the timer counter
    sei(); //enable interrupts
}

// Interrupt Service Routine for Timer1 Overflow
ISR(TIMER1_OVF_vect) {
    timerOverflowCount++;  // Increment the overflow counter
}

void waitForMinute() {
    const uint16_t requiredOverflows = (60) / 4.194; // Calculate required overflows (~14 for 16MHz clock)

    timerOverflowCount = 0; // Reset the counter
    set_sleep_mode(SLEEP_MODE_IDLE); // Use Idle mode for sleep

    while (timerOverflowCount < requiredOverflows) {
        // Enable sleep mode
        sleep_enable();

        // Enter sleep mode
        sleep_cpu();

        // MCU wakes up here when Timer1 interrupt triggers
        sleep_disable();
    }
    // Timer reached 1 minute, continue execution
}


void setup() {
  // Initialize Serial for debugging
  Serial.begin(9600);
  while (!Serial);

  
  // Initialize I2C
  Wire.begin(); // This uses PC0 (SCL) and PC1 (SDA) by default on ATmega644A

  // Initialize the RadioHead driver
  driver.init();

  // Initialize sensors
  sensors.begin();

  setupTimer1();

  if (!bmp.begin(BMP_CS)) { // Initialize BMP280 with SPI
    Serial.println("Error: BMP280 not found!");
    while (1); // Halt if BMP280 initialization fails
  }

  bmp.setSampling(Adafruit_BMP280::MODE_FORCED,
                  Adafruit_BMP280::SAMPLING_X2,
                  Adafruit_BMP280::SAMPLING_X16,
                  Adafruit_BMP280::FILTER_X16,
                  Adafruit_BMP280::STANDBY_MS_500);

  // Indicate setup completion
  Serial.println("Setup completed. Starting measurements...");
  pinMode(BMP_CS, OUTPUT);
  pinMode(19, OUTPUT);
  pinMode(3, OUTPUT);
  digitalWrite(3, HIGH);
}

void loop() {
  // Measure temperature
  measure_temperature(&temp);
  if (temp == -127.0) {
    Serial.println("Error: Failed to read DS1820 temperature sensor. Retrying...");
  } else {
    Serial.println("lämpö mitattu");
  }
  floatValueArray[0] = temp;

  // Measure barometric pressure
  measure_barometric_pressure(&pressure);
  Serial.println("paine mitattu");
  floatValueArray[1] = pressure;


  // Measure relative humidity
  measure_relative_humidity(&humidity);
  Serial.println("kosteus mitattu");
  floatValueArray[2] = humidity;

  // Measure battery voltage
  measure_battery_voltage(&battery_voltage);
  Serial.println("akun jännite mitattu");
  floatValueArray[3] = battery_voltage;

  // Print results to Serial Monitor
  Serial.println("Sensor Readings:");
  Serial.print("Temperature (C): ");
  Serial.println(temp);
  Serial.print("Pressure (Pa): ");
  Serial.println(pressure);
  Serial.print("Humidity (%): ");
  Serial.println(humidity);
  Serial.print("Battery Voltage (V): ");
  Serial.println(battery_voltage);

  sendFloatArray();
  digitalWrite(3, HIGH);
  delay(5);  // Wait for a second before sending again
  digitalWrite(3, LOW);
  waitForMinute();
}

// Function to measure temperature
void measure_temperature(float* temp_ptr) {
  sensors.requestTemperatures();
  *temp_ptr = sensors.getTempCByIndex(0);
  // Retry logic for invalid readings
  if (*temp_ptr == -127.0) {
    delay(200); // Short delay before retry
    sensors.requestTemperatures();
    *temp_ptr = sensors.getTempCByIndex(0);
  }
}

// Function to measure barometric pressure
void measure_barometric_pressure(float* pressure_ptr) {
  bmp.takeForcedMeasurement();
  *pressure_ptr = bmp.readPressure();
}

// Function to measure relative humidity
void measure_relative_humidity(float* humidity_ptr) {
  if (humidity_ptr == NULL) {
    Serial.println("Error: Null pointer passed to measure_relative_humidity");
    return;
  }

  uint8_t buf[4] = {0};
  if (readReg(0x00, buf, 4)) { // Adjust register address as per sensor datasheet
    uint16_t rawHumidity = (buf[2] << 8) | buf[3];
    *humidity_ptr = ((float)rawHumidity / 65535.0) * 100.0;
  } else {
    Serial.println("Error: Failed to read humidity data");
  }
}

// Function to measure battery voltage
void measure_battery_voltage(float* battery_voltage_ptr) {
  digitalWrite(19, LOW);          // Enable CS for battery level
  delay(10);
  *battery_voltage_ptr = analogRead(A0) * (((5.0+0.03) / 1023.0)); // skaalaa tämä vielä
  delay(10);
  digitalWrite(19, HIGH);         // Disable CS
}

// Function to read a register via I2C
uint8_t readReg(uint8_t reg, void* pBuf, size_t size) {
  if (pBuf == NULL) {
    Serial.println("Error: Null pointer passed to readReg");
    return 0;
  }

  Wire.beginTransmission(ADDRESS);
  Wire.write(reg);
  if (Wire.endTransmission() != 0) {
    return 0;
  }

  delay(20); // Allow sensor response time
  Wire.requestFrom((uint8_t)ADDRESS, (uint8_t)size);
  for (size_t i = 0; i < size; i++) {
    ((uint8_t*)pBuf)[i] = Wire.read();
  }
  return size;
}

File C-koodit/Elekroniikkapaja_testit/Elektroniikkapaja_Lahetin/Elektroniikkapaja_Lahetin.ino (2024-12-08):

//Include libraries
#include <OneWire.h>
#include <DallasTemperature.h>
#include <RH_ASK.h>
#include <SPI.h> 
#include <Adafruit_BMP280.h>
#include <Wire.h>

//pin definition
#define ONE_WIRE_BUS (PC2)
#define BMP_SCK  (PB7)
#define BMP_MISO (PB6)
#define BMP_MOSI (PB7)
#define BMP_CS   (PB2)
#define address 0x40 //SEN0546 I2C address

//global variables
float temp = 0.0;
float pressure = 0.0;
float humidity = 0.0; 
float battery_voltage = 0.0;
uint8_t buf[4] = {0};
uint16_t rawHumidity;

//function prototypes
void transmit_data_packet()
void measure_barometric_pressure(float* pressure_ptr);
void measure_relative_humidity(float* humidity_ptr);
void measure_temperature(float* temp_ptr);
void measure_battery_voltage(float* battery_voltage);
uint8_t readReg(uint8_t reg, void* pBuf, size_t size);
//void measure_brightness();


//Initialize dallas temp ds1820
OneWire oneWire(ONE_WIRE_BUS);        // Setup a oneWire instance to communicate with any OneWire devices (not just Maxim/Dallas temperature ICs)
DallasTemperature sensors(&oneWire);  // Pass our oneWire reference to Dallas Temperature. 

//initialize BMP280
Adafruit_BMP280 bmp(BMP_CS); // hardware SPI

void setup() {
  // put your setup code here, to run once:
  pinMode(A0, INPUT);   //battery level
  pinMode(A1, INPUT);   //LDR
  pinMode(PB1, OUTPUT); //CS LDR
  pinMode(PB2, OUTPUT); //CS BMP280
  pinMode(PB3, OUTPUT); //Int led
  pinMode(PB4, OUTPUT); //transmit ASK data pin
  pinMode(PC3, OUTPUT); //CS battery level

  digitalWrite(PC3, HIGH);

   //settings    KATSO TARVITSEEKO TÄTÄ!!!!!
  bmp.setSampling(Adafruit_BMP280::MODE_FORCED,     /* Operating Mode. */
                  Adafruit_BMP280::SAMPLING_X2,     /* Temp. oversampling */
                  Adafruit_BMP280::SAMPLING_X16,    /* Pressure oversampling */
                  Adafruit_BMP280::FILTER_X16,      /* Filtering. */
                  Adafruit_BMP280::STANDBY_MS_500); /* Standby time. */

  //initialize sensors
  sensors.begin();
  bmp.begin();
}

void loop() {

  //measure temperature
  measure_temperature(&temp);

  //measrue barometric pressure
  measure_barometric_pressure(&pressure);

  //measure relative humidity
  measure_relative_humidity(&humidity);
}

void measure_temperature(float* temp_ptr){
   sensors.requestTemperatures(); // Send the command to get temperatures
  * temp_ptr = sensors.getTempCByIndex(0);
}

void measure_barometric_pressure(float* pressure_ptr){
  bmp.takeForcedMeasurement(); // Send the command to get barometric pressure data
  * pressure_ptr = bmp.readPressure();
}

uint8_t readReg(uint8_t reg, void* pBuf, size_t size) {
  if (pBuf == NULL) {
    Serial.println("pBuf ERROR!! : null pointer");
    return 0;
  }
  uint8_t* _pBuf = (uint8_t*)pBuf;
  Wire.beginTransmission(address);
  Wire.write(&reg, 1);
  if (Wire.endTransmission() != 0) {
    return 0;
  }
  delay(20); // Small delay for sensor response
  Wire.requestFrom(address, (uint8_t)size);
  for (uint16_t i = 0; i < size; i++) {
    _pBuf[i] = Wire.read();
  }
  return size;
}

void measure_relative_humidity(float* humidity_ptr){
   if (hum == NULL) {
    Serial.println("Error: null pointer passed to measureHumidity");
    return;
  }

  uint8_t buf[4] = {0};
  uint16_t rawHumidity;

  // Read humidity register (0x00 is assumed as register for simplicity)
  if (readReg(0x00, buf, 4)) {
    rawHumidity = buf[2] << 8 | buf[3];
    *hum = ((float)rawHumidity / 65535.0) * 100; // Update the value at the pointer
  } 
}

void measure_battery_voltage(float* battery_voltage){
  digitalWrite(PC3, LOW); //cs enable for reading votlage
  * battery_voltage = analogRead(A0);
  digitalWrite(PC3, HIGH);
}

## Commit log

2024-10-14 Kicadi projekti
    [Elektroniikkapaja.kicad_pcb, Elektroniikkapaja.kicad_sch]
2024-10-20 testaus onko oikea versio
    [Elektroniikkapaja-vastaanotin.kicad_pcb, Elektroniikkapaja-vastaanotin.kicad_sch, Elektroniikkapaja.kicad_sch]
2024-10-20 tää pitäs olla oikea versio
    [Elektroniikkapaja-vastaanotin.kicad_pcb, Elektroniikkapaja-vastaanotin.kicad_sch, Elektroniikkapaja.kicad_pcb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]
2024-10-21 updates to schematic
2024-10-23 Lähetin ja vastaanotin kicad
    [Elektroniikkapaja-vastaanotin.kicad_pcb, Elektroniikkapaja-vastaanotin.kicad_sch, Elektroniikkapaja.kicad_pcb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]
2024-11-11 nyt on valmista levyä
    [Elektroniikkapaja-B_Cu.gbr, Elektroniikkapaja-B_Mask.gbr, Elektroniikkapaja-B_Paste.gbr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]
2024-12-01 Temperature reading application
2024-12-29 Siivoilua ja webi-tiedostot kuntoon
    [Elektroniikkapaja.kicad_sch]
2024-12-29 Poistin raspitiedoston, kun se oli vanha
    [weather_data.csv]
